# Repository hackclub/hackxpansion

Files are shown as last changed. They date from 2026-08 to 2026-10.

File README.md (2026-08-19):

<h1 align="center">
    Hackxpansion
</h1>

<h3 align="center">
    <a href="https://hackxpansion.koeg.dev">Website</a>
    <br/>
</h3>

<h4 align="center">
    A handheld console with 4 expansion solts
</h4>

<div align="center">
    
</div>

## Key Features

- Resistor based module identification at start up
- [2" 240x320 ST7789 LCD panel](https://www.buydisplay.com/2-inch-ips-tft-lcd-display-ips-panel-screen-240x320-for-smart-watch)
- RP2354 MCU
- Easily adaptable [module standard](https://hackxpansion.dino.icu/docs/detailed/card)
- Rust firmware with [embassy](https://embassy.dev/) and [slint-ui](https://slint.dev/)

## Why?

I really like the idea of modules, and modular things, and making people work together, so I made this.

## PCB

The console has two 4 layer PCBs designed in KiCAD, a main-board and a daughter-board, designed for JLC's basic process. 

irl pcb without some connectors and swithc

### Main-Board

main-board schematic
main-board pcb
main-board render

### Daughter-Board

daughter-board schematic
daughter-board pcb
daughter-board render

## Making Your Own Modules

There are three simple steps to making your own module:

1. Design the module PCB in KiCAD
2. Design the module case in CAD
3. Write a driver for the module

There are detailed docs on the [hackxpansion website](https://hackxpansion.dino.icu/docs)

## Case

The case is designed in Autodesk Fusion, there are .f3z files in the hardware directory.

The models have parameters that can be adjusted to fit your needs.

## Shoutouts

Thank you so much for [Simon](https://github.com/NEOgHacking) who helped with the fanout of the RP, and also gave a ton of constructive feedback!!!!

## Zine

magazine page

## BOM for Console

This is for an order of 2 PCBA PCBs.

Also found in a [CSV file](hardware/hackxpansion/BOM.csv). Each component has an LCSC part number attached that can be used to find the component on the LCSC website.

|Item |Price per unit|Nr of units|Total price|Link |
|---|---|---|---|---|
|PCB with PCBA |$60.00 |1 |$60.00 |https://jlcpcb.com/ |
|Display |$4.36 |1 |$4.36 |https://www.buydisplay.com/2-inch-ips-tft-lcd-display-ips-panel-screen-240x320-for-smart-watch|
|2x7 2.54mm header |$0.386 |10 |$3.860 |https://www.aliexpress.com/item/1005012166781874.html |
|Battery 502035 |$6.64 |1 |$6.64 |https://www.aliexpress.com/item/1005008218024646.html |
|M2 OD3 L2 heat set insert |$0.0696 |15 |$1.0440 |https://www.aliexpress.com/item/1005006798286851.html |
|M2 L6 screw |$0.0766 |5 |$0.3830 |https://www.aliexpress.com/item/4000970993800.html |
|M2 L8 screw |$0.0766 |2 |$0.1532 |https://www.aliexpress.com/item/4000970993800.html |
|M2 L4 screw |$0.0766 |8 |$0.6128 |https://www.aliexpress.com/item/4000970993800.html |
| | |Total: |$77.05 | |

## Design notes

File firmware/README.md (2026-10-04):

# Xpanse

> [!WARNING]  
> This is still under development and may contain bugs, and the api may change, and many parts aren't documented.

This is the firmware for the Hackxpansion console.

The main binary crate is called `xpanse`; this is the create the is the heart of the firmware.

The driver api is located in the `xpanse-api` crate; this crate provides drivers and apps with the necessary traits and types that they need to implement.

## Enabling apps

Each app can be enabled by a feature flag; you can find the exact names for these in the `Cargo.toml` of the `xpanse` folder under the `[features]` section.

You can enable features by adding `--features "app-name1,app-name2,app-name3"

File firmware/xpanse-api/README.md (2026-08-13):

# Xpanse API

Shared API for xpanse apps, module drivers, and platform firmware for the [Hackxpansion](https://github.com/hackclub/hackxpansion) console

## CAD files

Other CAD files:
hardware/hackxpansion/hackx.f3z

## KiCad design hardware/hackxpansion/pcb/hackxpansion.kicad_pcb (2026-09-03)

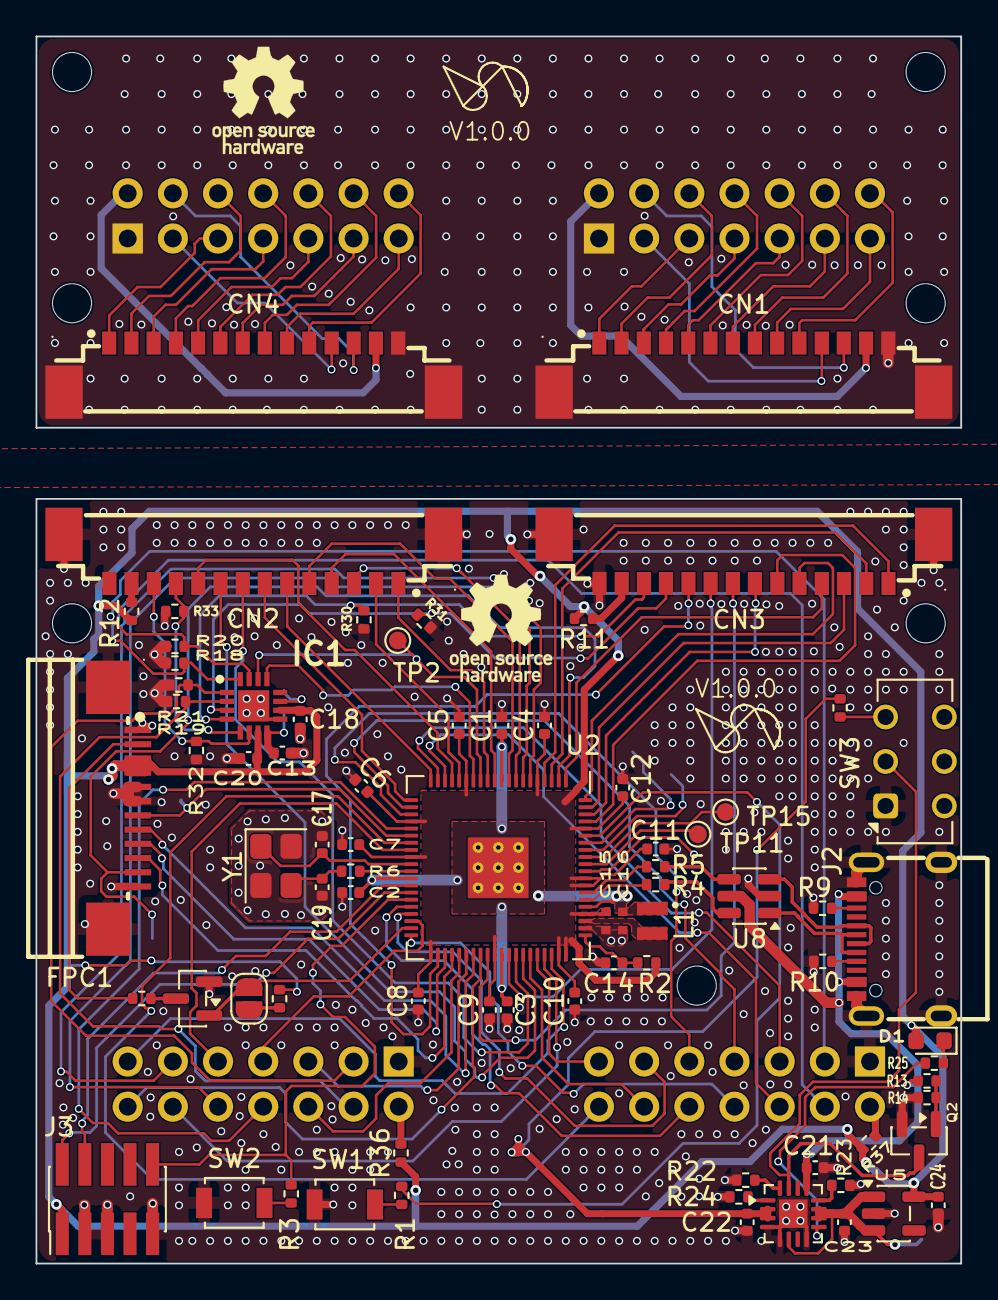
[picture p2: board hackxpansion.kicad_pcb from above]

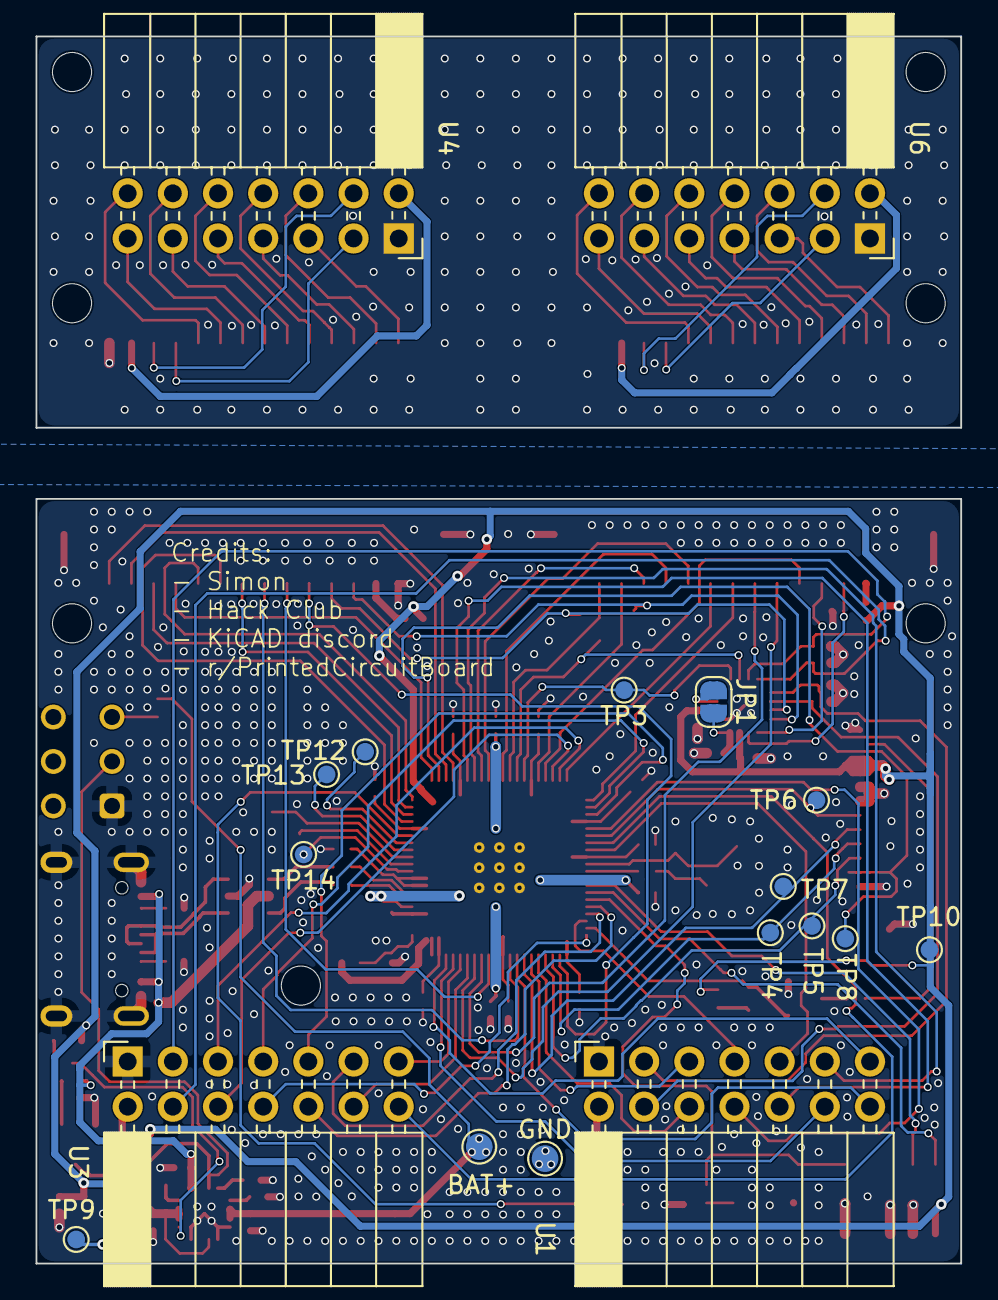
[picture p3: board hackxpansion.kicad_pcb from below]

Board: 4 copper layers, 52.0 x 43.0 mm, 104 parts (21 on the bottom side), 130 nets.

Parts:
BAT+: TestPoint; TestPoint_Pad_D1.5mm
C1, C3, C4, C5, C6, C7, C8, C9, C10, C11, C12: 100n; C_0402_1005Metric
C2, C14, C21, C22, C23, C24: 4u7; C_0402_1005Metric
C13, C18, C20: 1u; C_0402_1005Metric
C15, C16: 4u7; C_0402_1005Metric_small_pads
C17, C19: 15p; C_0402_1005Metric
CN1, CN2, CN3, CN4: 533981471; CONN-SMD_14P-P1.25_MOLEX_533981471
D1: LED; LED_0603_1608Metric
FPC1: AFC08-S12ECA-00; FPC-SMD_P0.80-12P_LCS-SJ-H2.0
GND: TestPoint; TestPoint_Pad_D1.5mm
H1, H2, H3, H4, H5, H6, H7: MountingHole; MountingHole_2.2mm_M2
IC1: ADS7128IRTET; QFN50P300X300X80-17N-D
J2: USB_C_Receptacle_USB2.0_14P; USB-C-SMD_TYPE-C-16PIN-2MD-073
J3: Conn_ARM_JTAG_SWD_10; PinHeader_2x05_P1.27mm_Vertical_SMD
JP1, JP3: SolderJumper_2_Open; SolderJumper-2_P1.3mm_Open_RoundedPad1.0x1.5mm
L1: 3u3; L_pol_2016
Q1: BSS138; SOT-23
Q2: 2N7002; SOT-23
R1, R3, R6: 1k; R_0402_1005Metric
R2: 33R; R_0402_1005Metric
R4, R5: 27R; R_0402_1005Metric
R7: 10R; R_0402_1005Metric
R8, R14, R18, R19, R20, R21, R24, R30, R31, R32, R33: 10k; R_0402_1005Metric
R9, R10: 5k1; R_0402_1005Metric
R11, R12, R36, R37: 5R1; R_0402_1005Metric
R13: 100R; R_0402_1005Metric
R15: 100k; R_0402_1005Metric
R22: 3k3; R_0402_1005Metric
R23, R25: 1k5; R_0402_1005Metric
SW1, SW2: SW_Push; SW_SPST_B3U-1000P
SW3: SW_On_Off; SW_CK_JS202011AQN_DPDT_Angled
SYM1, SYM2: Logo_Open_Hardware_Small; OSHW-Logo_5.7x6mm_SilkScreen
TP2, TP3, TP4, TP5, TP6, TP7, TP8, TP9, TP10, TP11, TP12, TP13, TP14, TP15: TestPoint; TestPoint_Pad_D1.0mm
U1, U3, U4, U6: PinSocket_2x07_P2.54mm_Horizontal
U2: RP2354B; RP2350-QFN-80-1EP_10x10_P0.4mm_EP3.4x3.4mm_ThermalVias
U5: SPX3819M5-L-3-3; SOT-23-5
U7: BQ24075RGT; VQFN-16-1EP_3x3mm_P0.5mm_EP1.6x1.6mm
U8: USBLC6-2SC6; SOT-23-6
Y1: ABM8-272-T3; Crystal_SMD_3225-4Pin_3.2x2.5mm

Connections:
+1V1: C1.1, C2.1, C3.1, C16.1, L1.1, U2.10 (DVDD), U2.32 (DVDD), U2.51 (DVDD), U2.65 (VREG_FB)
/+3V3: C4.1, C5.1, C6.1, C7.1, C8.1, C9.1, C10.1, C11.1, C12.1, C15.1, C18.1, C20.1, C24.2, D1.2 (A), FPC1.3, FPC1.4, IC1.7 (AVDD), IC1.10 (DVDD), J3.1 (VTref), R2.1, R8.2, R11.1, R12.1, R36.1, R37.1, TP10.1 (1_1), U2.5 (IOVDD), U2.15 (IOVDD), U2.24 (IOVDD), U2.29 (IOVDD), U2.41 (IOVDD), U2.50 (IOVDD), U2.59 (ADC_AVDD), U2.60 (IOVDD), U2.64 (VREG_VIN), U2.68 (USB_OTP_VDD), U2.69 (QSPI_IOVDD), U2.76 (IOVDD), U5.5 (OUT)
/Connector Daughter Mod2/bank.GPIO0: CN1.1, U4.5 (GPIO0)
/Connector Daughter Mod2/bank.GPIO1: CN1.2, U4.6 (GPIO1)
/Connector Daughter Mod2/bank.GPIO2: CN1.3, U4.7 (GPI02)
/Connector Daughter Mod2/bank.GPIO3: CN1.4, U4.8 (GPIO3)
/Connector Daughter Mod2/bank.GPIO4: CN1.5, U4.9 (GPIO4)
/Connector Daughter Mod2/bank.GPIO5: CN1.6, U4.10 (GPIO5)
/Connector Daughter Mod2/bank.GPIO6: CN1.7, U4.11 (GPIO6)
/Connector Daughter Mod2/bank.GPIO7: CN1.8, U4.12 (GPIO7)
/Connector Daughter Mod2/bank.GPIO8: CN1.9, U4.13 (GPIO8)
/Connector Daughter Mod2/bank.GPIO9: CN1.10, U4.14 (GPIO9)
/Connector Daughter Mod2/mod.MD0: CN1.11, U4.3 (MD0)
/Connector Daughter Mod2/mod.MD1: CN1.12, U4.4 (MD1)
/Connector Daughter Mod3/bank.GPIO0: CN4.1, U6.5 (GPIO0)
/Connector Daughter Mod3/bank.GPIO1: CN4.2, U6.6 (GPIO1)
/Connector Daughter Mod3/bank.GPIO2: CN4.3, U6.7 (GPI02)
/Connector Daughter Mod3/bank.GPIO3: CN4.4, U6.8 (GPIO3)
/Connector Daughter Mod3/bank.GPIO4: CN4.5, U6.9 (GPIO4)
/Connector Daughter Mod3/bank.GPIO5: CN4.6, U6.10 (GPIO5)
/Connector Daughter Mod3/bank.GPIO6: CN4.7, U6.11 (GPIO6)
/Connector Daughter Mod3/bank.GPIO7: CN4.8, U6.12 (GPIO7)
/Connector Daughter Mod3/bank.GPIO8: CN4.9, U6.13 (GPIO8)
/Connector Daughter Mod3/bank.GPIO9: CN4.10, U6.14 (GPIO9)
/Connector Daughter Mod3/mod.MD0: CN4.11, U6.3 (MD0)
/Connector Daughter Mod3/mod.MD1: CN4.12, U6.4 (MD1)
/Connector Main Mod2/+3V3: CN3.13, R11.2
/Connector Main Mod2/bank.GPIO0: CN3.1, U2.4 (GPIO7)
/Connector Main Mod2/bank.GPIO1: CN3.2, U2.3 (GPIO6)
/Connector Main Mod2/bank.GPIO2: CN3.3, U2.79 (GPIO2)
/Connector Main Mod2/bank.GPIO3: CN3.4, U2.1 (GPIO4)
/Connector Main Mod2/bank.GPIO4: CN3.5, U2.80 (GPIO3)
/Connector Main Mod2/bank.GPIO5: CN3.6, U2.77 (GPIO0)
/Connector Main Mod2/bank.GPIO6: CN3.7, U2.78 (GPIO1)
/Connector Main Mod2/bank.GPIO7: CN3.8, U2.49 (GPIO40/ADC0)
/Connector Main Mod2/bank.GPIO8: CN3.9, U2.52 (GPIO41/ADC1)
/Connector Main Mod2/bank.GPIO9: CN3.10, U2.42 (GPIO33)
/Connector Main Mod2/mod.MD0: CN3.11, IC1.3 (AIN4/GPIO4), R31.1
/Connector Main Mod2/mod.MD1: CN3.12, IC1.4 (AIN5/GPIO5), R30.1
/Connector Main Mod3/+3V3: CN2.13, R12.2
/Connector Main Mod3/bank.GPIO0: CN2.1, U2.12 (GPIO13)
/Connector Main Mod3/bank.GPIO1: CN2.2, U2.16 (GPIO16)
/Connector Main Mod3/bank.GPIO2: CN2.3, U2.8 (GPIO10)
/Connector Main Mod3/bank.GPIO3: CN2.4, U2.11 (GPIO12)
/Connector Main Mod3/bank.GPIO4: CN2.5, U2.9 (GPIO11)
/Connector Main Mod3/bank.GPIO5: CN2.6, U2.20 (GPIO20)
/Connector Main Mod3/bank.GPIO6: CN2.7, U2.21 (GPIO21)
/Connector Main Mod3/bank.GPIO7: CN2.8, U2.53 (GPIO42/ADC2)
/Connector Main Mod3/bank.GPIO8: CN2.9, U2.54 (GPIO43/ADC3)
/Connector Main Mod3/bank.GPIO9: CN2.10, U2.17 (GPIO17)
/Connector Main Mod3/mod.MD0: CN2.11, IC1.5 (AIN6/GPIO6), R33.1
/Connector Main Mod3/mod.MD1: CN2.12, IC1.6 (AIN7/GPIO7), R32.1
/DAUGHT_GND: CN1.14, CN1.15, CN1.16, CN4.14, CN4.15, CN4.16, U4.1 (GND), U6.1 (GND)
/Daughter Board/+3V3_MOD2: CN1.13, U4.2 (3V3)
/Daughter Board/+3V3_MOD3: CN4.13, U6.2 (3V3)
/GND: C1.2, C2.2, C3.2, C4.2, C5.2, C6.2, C7.2, C8.2, C9.2, C10.2, C11.2, C12.2, C13.2, C14.2, C15.2, C16.2, C17.1, C18.2, C19.1, C20.2, C21.1, C22.1, C23.1, C24.1, CN2.14, CN2.15, CN2.16, CN3.14, CN3.15, CN3.16, FPC1.1, FPC1.5, FPC1.6, FPC1.12, FPC1.13, FPC1.14, GND.1 (1_1), IC1.9 (GND), IC1.17 (EP), J2.A1 (GND), J2.A12 (GND), J2.B1 (GND), J2.B12 (GND), J2.SH (SHIELD), J3.3 (GND), J3.5 (GND), J3.9 (GNDDetect), Q1.2 (S), Q2.2 (S), R9.2, R10.2, R14.2, R18.2, R19.2, R20.2, R21.2, R22.2, R23.2, R24.2, R30.2, R31.2, R32.2, R33.2, SW1.1, SW2.1, SW3.1 (A), U1.1 (GND), U2.62 (VREG_PGND), U2.81 (GND), U3.1 (GND), U5.2 (GND), U7.4 (~CE), U7.5 (EN2), U7.8 (VSS), U7.17 (VSS), U8.2 (GND), Y1.2 (G), Y1.4 (G)
/Main Board/ADC/SCL: IC1.13 (SCL), TP3.1 (1_1), U2.14 (GPIO15)
/Main Board/ADC/SDA: IC1.14 (SDA), TP2.1 (1_1), U2.13 (GPIO14)
/Main Board/ADC/mod0.MD0: IC1.1 (AIN2/GPIO2), R21.1, U1.3 (MD0)
/Main Board/ADC/mod0.MD1: IC1.2 (AIN3/GPIO3), R19.1, U1.4 (MD1)
/Main Board/ADC/mod1.MD0: IC1.15 (AIN0/GPIO0), R20.1, U3.3 (MD0)
/Main Board/ADC/mod1.MD1: IC1.16 (AIN1/GPIO1), R18.1, U3.4 (MD1)
/Main Board/Display/BACKLIGHT: JP3.2 (B), Q1.1 (G), U2.39 (GPIO31)
/Main Board/Display/CS: FPC1.8, TP7.1 (1_1), U2.47 (GPIO38)
/Main Board/Display/DC: FPC1.7, TP6.1 (1_1), U2.26 (GPIO25)
/Main Board/Display/MOSI: FPC1.10, TP5.1 (1_1), U2.44 (GPIO35)
/Main Board/Display/RESET: FPC1.11, TP8.1 (1_1), U2.2 (GPIO5)
/Main Board/Display/SCLK: FPC1.9, TP4.1 (1_1), U2.43 (GPIO34)
/Main Board/Module Bay 0/+3V3: R36.2, U1.2 (3V3)
/Main Board/Module Bay 0/GPIO0: U1.5 (GPIO0), U2.46 (GPIO37)
/Main Board/Module Bay 0/GPIO1: U1.6 (GPIO1), U2.45 (GPIO36)
/Main Board/Module Bay 0/GPIO2: U1.7 (GPI02), U2.38 (GPIO30)
/Main Board/Module Bay 0/GPIO3: U1.8 (GPIO3), U2.25 (GPIO24)
/Main Board/Module Bay 0/GPIO4: U1.9 (GPIO4), U2.28 (GPIO27)
/Main Board/Module Bay 0/GPIO5: U1.10 (GPIO5), U2.6 (GPIO8)
/Main Board/Module Bay 0/GPIO6: U1.11 (GPIO6), U2.7 (GPIO9)
/Main Board/Module Bay 0/GPIO7: U1.12 (GPIO7), U2.57 (GPIO46/ADC6)
/Main Board/Module Bay 0/GPIO8: U1.13 (GPIO8), U2.58 (GPIO47/ADC7)
/Main Board/Module Bay 0/GPIO9: U1.14 (GPIO9), U2.48 (GPIO39)
/Main Board/Module Bay 1/+3V3: R37.2, U3.2 (3V3)
/Main Board/Module Bay 1/GPIO0: U2.19 (GPIO19), U3.5 (GPIO0)
/Main Board/Module Bay 1/GPIO1: U2.18 (GPIO18), U3.6 (GPIO1)
/Main Board/Module Bay 1/GPIO2: U2.22 (GPIO22), U3.7 (GPI02)
/Main Board/Module Bay 1/GPIO3: U2.40 (GPIO32), U3.8 (GPIO3)
/Main Board/Module Bay 1/GPIO4: U2.23 (GPIO23), U3.9 (GPIO4)
/Main Board/Module Bay 1/GPIO5: U2.36 (GPIO28), U3.10 (GPIO5)
/Main Board/Module Bay 1/GPIO6: U2.37 (GPIO29), U3.11 (GPIO6)
/Main Board/Module Bay 1/GPIO7: U2.55 (GPIO44/ADC4), U3.12 (GPIO7)
/Main Board/Module Bay 1/GPIO8: U2.56 (GPIO45/ADC5), U3.13 (GPIO8)
/Main Board/Module Bay 1/GPIO9: U2.27 (GPIO26), U3.14 (GPIO9)
/Main Board/Power/+BATT: BAT+.1 (1_1), C22.2, R15.1, U7.2 (BAT), U7.3 (BAT)
/Main Board/Power/ILIM: R23.1, U7.12 (ILIM)
/Main Board/Power/ISET: R22.1, U7.16 (ISET)
/Main Board/Power/REG-OUT: C23.2, TP9.1 (1_1), U5.1 (IN), U5.3 (EN), U7.6 (EN1), U7.10 (OUT), U7.11 (OUT)
/Main Board/Power/SYSOFF: Q2.3 (D), SW3.2 (B), U7.15 (SYSOFF)
/Main Board/Power/TS: R24.1, U7.1 (TS)
/Main Board/Power/VBUS: C21.2, J2.A4 (VBUS), J2.A9 (VBUS), J2.B4 (VBUS), J2.B9 (VBUS), R13.1, U7.13 (IN), U8.5 (VBUS)
/Main Board/RP2354B/D+: R5.1, U8.4 (I/O2)
/Main Board/RP2354B/D-: R4.1, U8.6 (I/O1)
/Main Board/RP2354B/QSPI_SS: R1.2, U2.75 (~QSPI_SS)
/Main Board/RP2354B/RUN: J3.10 (~RESET), R3.2, U2.35 (RUN)
/Main Board/RP2354B/SWCLK: J3.4 (SWCLK/TCK), U2.33 (SWCLK)
/Main Board/RP2354B/SWDIO: J3.2 (SWDIO/TMS), U2.34 (SWDIO)
/Main Board/RP2354B/~USB_BOOT: R1.1, SW1.2
/Main Board/USB/CC1: J2.A5 (CC1), R10.1
/Main Board/USB/CC2: J2.B5 (CC2), R9.1
/Main Board/USB/DIRTY_D+: J2.A6 (D+), J2.B6 (D+), U8.3 (I/O2)
/Main Board/USB/DIRTY_D-: J2.A7 (D-), J2.B7 (D-), U8.1 (I/O1)
unnamed: C19.2, R6.1, Y1.3
unnamed: D1.1 (K), R25.1
unnamed: FPC1.2, R7.2
unnamed: IC1.11 (ADDR), JP1.1 (A)
unnamed: C13.1, IC1.8 (DECAP), JP1.2 (B)
unnamed: JP3.1 (A), R8.1
unnamed: Q1.3 (D), R7.1
unnamed: Q2.1 (G), R13.2, R14.1
unnamed: R3.1, SW2.2
unnamed: R15.2, SW3.3 (C)
unnamed: TP11.1 (1_1), U2.71 (QSPI_SCLK)
unnamed: TP15.1 (1_1), U2.72 (QSPI_SD0)
unnamed: TP12.1 (1_1), U2.74 (QSPI_SD1)
unnamed: TP13.1 (1_1), U2.73 (QSPI_SD2)
unnamed: TP14.1 (1_1), U2.70 (QSPI_SD3)
unnamed: R4.2, U2.66 (USB_DM)
unnamed: R5.2, U2.67 (USB_DP)
unnamed: C14.1, R2.2, U2.61 (VREG_AVDD)
unnamed: L1.2, U2.63 (VREG_LX)
unnamed: C17.2, U2.30 (XIN), Y1.1
unnamed: R6.2, U2.31 (XOUT)
unnamed: R25.2, U7.9 (~CHG)

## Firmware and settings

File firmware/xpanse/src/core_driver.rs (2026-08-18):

use xpanse_api::gpio_bank::GpioBank;
use xpanse_api::registry::Registry;

use crate::load_driver::load_driver_pair;
use crate::{adc::init_adc, adc_mapping, resource_split::*};
use xpanse_api::bus::allocator::BusAllocator;
use xpanse_api::interfaces::adc;
use xpanse_api::interfaces::usb::UsbPeripheral;
use xpanse_api::metadata::{ModuleID, ModuleSlot};

use embassy_sync::{blocking_mutex::raw::CriticalSectionRawMutex, signal::Signal};
use embassy_time::{Duration, Timer, with_timeout};

const MODULE_DETECTION_TIMEOUT: Duration = Duration::from_millis(100);

macro_rules! gpio_bank_from_peris {
    ($peri:expr) => {
        GpioBank::new(
            $peri.gpio0,
            $peri.gpio1,
            $peri.gpio2,
            $peri.gpio3,
            $peri.gpio4,
            $peri.gpio5,
            $peri.gpio6,
            $peri.gpio7,
            $peri.gpio8,
            $peri.gpio9,
            $peri.pwm_slice1,
            $peri.pwm_slice2,
            $peri.pwm_slice3,
        )
    };
}

static REGISTRY_HANDOFF: Signal<CriticalSectionRawMutex, Registry> = Signal::new();

pub async fn take_registry() -> Registry {
    REGISTRY_HANDOFF.wait().await
}

#[embassy_executor::task]
pub async fn app_core_task(
    gpio_bank_0: GpioBankPeris0,
    gpio_bank_1: GpioBankPeris1,
    gpio_bank_2: GpioBankPeris2,
    gpio_bank_3: GpioBankPeris3,
    mut i2c_pins: I2cPinPeris,
    remaining_peris: RemainingPeris,
) {
    defmt::info!("app_core: started on core 1");

    let gpio_bank_0 = gpio_bank_from_peris!(gpio_bank_0);
    let gpio_bank_1 = gpio_bank_from_peris!(gpio_bank_1);
    let gpio_bank_2 = gpio_bank_from_peris!(gpio_bank_2);
    let gpio_bank_3 = gpio_bank_from_peris!(gpio_bank_3);
    defmt::info!("app_core: GPIO banks initialized");

    defmt::info!("app_core: initializing module-detection ADC");
    let module_ids = {
        let module_adc = match init_adc(i2c_pins.sda.reborrow(), i2c_pins.scl.reborrow()).await {
            Ok(adc) => {
                defmt::info!("app_core: module-detection ADC initialized");
                Some(adc)
            }
            Err(error) => {
                defmt::error!(
                    "app_core: module-detection ADC initialization failed: {:?}",
                    error
                );
                None
            }
        };

        match module_adc {
            Some(mut module_adc) => {
                let front_right = detect_module(&mut module_adc, ModuleSlot::FrontRight).await;
                let front_left = detect_module(&mut module_adc, ModuleSlot::FrontLeft).await;
                let back_right = detect_module(&mut module_adc, ModuleSlot::BackRight).await;
                let back_left = detect_module(&mut module_adc, ModuleSlot::BackLeft).await;
                [front_right, front_left, back_right, back_left]
            }
            None => [None; 4],
        }
    };

    defmt::info!("app_core: initializing internal ADC");
    adc::init_adc(remaining_peris.adc, remaining_peris.adc_temp);
    defmt::info!("app_core: internal ADC initialized");

    defmt::info!("app_core: creating bus allocator");
    let mut bus_allocator = BusAllocator::new(
        None,
        Some(remaining_peris.spi1),
        Some(remaining_peris.i2c0),
        Some(remaining_peris.i2c1),
        Some(remaining_peris.uart0),
        Some(remaining_peris.uart1),
        xpanse_api::bus::allocator::DmaPool {
            ch0: Some(remaining_peris.dma_ch0),
            ch1: Some(remaining_peris.dma_ch1),
            ch2: Some(remaining_peris.dma_ch2),
            ch3: Some(remaining_peris.dma_ch3),
            ch4: Some(remaining_peris.dma_ch4),
            ch5: Some(remaining_peris.dma_ch5),
            ch6: Some(remaining_peris.dma_ch6),
            ch7: Some(remaining_peris.dma_ch7),
            ch8: Some(remaining_peris.dma_ch8),
            ch9: Some(remaining_peris.dma_ch9),
            ch10: Some(remaining_peris.dma_ch10),
            ch11: Some(remaining_peris.dma_ch11),
            ch12: Some(remaining_peris.dma_ch12),
            ch13: Some(remaining_peris.dma_ch13),
            ch14: Some(remaining_peris.dma_ch14),
            ch15: Some(remaining_peris.dma_ch15),
        },
        remaining_peris.pio0,
        remaining_peris.pio1,
        remaining_peris.pio2,
    );

    let mut registry = Registry::new();
    registry.register_platform::<UsbPeripheral>(remaining_peris.usb);

    defmt::info!("app_core: loading module drivers");
    load_driver_pair(
        (
            (module_ids[0], gpio_bank_0, ModuleSlot::FrontRight),
            (module_ids[1], gpio_bank_1, ModuleSlot::FrontLeft),
        ),
        &mut registry,
        &mut bus_allocator,
    )
    .await;
    load_driver_pair(
        (
            (module_ids[2], gpio_bank_2, ModuleSlot::BackRight),
            (module_ids[3], gpio_bank_3, ModuleSlot::BackLeft),
        ),
        &mut registry,
        &mut bus_allocator,
    )
    .await;

    defmt::info!("app_core: drivers loaded, handing registry to core 0");
    REGISTRY_HANDOFF.signal(registry);
}

async fn detect_module(adc: &mut crate::adc::Adc<'_>, slot: ModuleSlot) -> Option<ModuleID> {
    defmt::info!("app_core: detecting module in {:?}", slot);

    for attempt in 1..=3 {
        match with_timeout(MODULE_DETECTION_TIMEOUT, adc_mapping::map_adc(adc, slot)).await {
            Ok(Ok(Some(id))) => {
                defmt::info!("app_core: detected module {:?} in {:?}", id, slot);
                return Some(id);
            }
            Ok(Ok(None)) => {
                defmt::info!("app_core: no module detected in {:?}", slot);
                return None;
            }
            Ok(Err(error)) => defmt::warn!(
                "app_core: module detection attempt {} failed for {:?}: {:?}",
                attempt,
                slot,
                error
            ),
            Err(_) => defmt::warn!(
                "app_core: module detection attempt {} timed out for {:?}",
                attempt,
                slot
            ),
        }
        Timer::after_millis(10).await;
    }
    defmt::error!("app_core: module detection failed for {:?}", slot);
    None
}

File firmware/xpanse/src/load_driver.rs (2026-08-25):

use xpanse_api::{
    bus::allocator::BusAllocator,
    driver::{Driver, DriverMeta},
    gpio_bank::{BankPins, GpioBank},
    metadata::{ModuleID, ModuleSlot},
    registry::Registry,
};

type Module<G> = (Option<ModuleID>, GpioBank<G>, ModuleSlot);

/// loads a dual slot driver or two single slot drivers
///
/// 0 is right, 1 is left for modules
pub async fn load_driver_pair<G1: BankPins, G2: BankPins>(
    modules: (Module<G1>, Module<G2>),
    registry: &mut Registry,
    bus: &mut BusAllocator,
) {
    match (modules.0.0, modules.1.0) {
        (None, None) => {
            defmt::warn!("No modules in slots: {:?} {:?} ", modules.0.2, modules.1.2);
        }

        (Some(right), Some(left)) if left != right => {
            load_driver(modules.0.0, modules.0.1, modules.0.2, registry, bus).await;
            load_driver(modules.1.0, modules.1.1, modules.1.2, registry, bus).await;
        }

        (Some(id), None) | (None, Some(id)) | (Some(id), Some(_)) => {
            if let Err(banks) = load_dual_slot_driver(
                Some(id),
                (modules.0.1, modules.1.1),
                (modules.0.2, modules.1.2),
                registry,
                bus,
            )
            .await
            {
                load_driver(modules.0.0, banks.0, modules.0.2, registry, bus).await;
                load_driver(modules.1.0, banks.1, modules.1.2, registry, bus).await;
            }
        }
    }
}

async fn load_driver<G: BankPins>(
    id: Option<ModuleID>,
    bank: GpioBank<G>,
    slot: ModuleSlot,
    registry: &mut Registry,
    bus: &mut BusAllocator,
) {
    match id {
        Some(id) if id == four_button_driver::FourButtonDriver::ID => {
            match four_button_driver::FourButtonDriver::create(bank, slot, registry, bus).await {
                Ok(()) => defmt::info!("Four button driver initialized in {:?}", slot),
                Err(error) => {
                    defmt::error!("Four button driver init failed in {:?}: {:?}", slot, error)
                }
            }
        }
        Some(id) if id == two_button_driver::TwoButtonDriver::ID => {
            match two_button_driver::TwoButtonDriver::create(bank, slot, registry, bus).await {
                Ok(()) => defmt::info!("Two button driver initialized in {:?}", slot),
                Err(error) => {
                    defmt::error!("Two button driver init failed in {:?}: {:?}", slot, error)
                }
            }
        }
        Some(id) if id == test_driver::TestDriver::ID => {
            match test_driver::TestDriver::create(bank, slot, registry, bus).await {
                Ok(()) => defmt::info!("Test driver initialized in {:?}", slot),
                Err(error) => {
                    defmt::error!("Test driver init failed in {:?}: {:?}", slot, error)
                }
            }
        }
        Some(id) if id == test_driver::spi_adc::SpiAdcDriver::ID => {
            match test_driver::spi_adc::SpiAdcDriver::create(bank, slot, registry, bus).await {
                Ok(()) => defmt::info!("SPI ADC driver initialized in {:?}", slot),
                Err(error) => {
                    defmt::error!("SPI ADC driver init failed in {:?}: {:?}", slot, error)
                }
            }
        }

        Some(id) if id == wardriving_driver::WarDrivingDriver::ID => {
    match wardriving_driver::WarDrivingDriver::create(bank, slot, registry, bus).await {
        Ok(()) => defmt::info!("WarDriving driver initialized in {:?}", slot),
        Err(error) => {
            defmt::error!("WarDriving driver init failed in {:?}: {:?}", slot, error)
        }
    }
}

Some(id) if id == pn532_driver::Pn532Driver::ID => {
    match pn532_driver::Pn532Driver::create(bank, slot, registry, bus).await {
        Ok(()) => defmt::info!("PN532 driver initialized in {:?}", slot),
        Err(error) => {
            defmt::error!("PN532 driver init failed in {:?}: {:?}", slot, error)
        }
    }
}

        Some(id) if id == keebxpansion::KeebDriver::ID => {
            match keebxpansion::KeebDriver::create(bank, slot, registry, bus).await {
                Ok(()) => defmt::info!("Keeb driver initialized in {:?}", slot),
                Err(error) => {
                    defmt::error!("Keeb driver init failed in {:?}: {:?}", slot, error)
                }
            }
        }
        Some(id) if id == nfcxpansion::NfcDriver::ID => {
            match nfcxpansion::NfcDriver::create(bank, slot, registry, bus).await {
                Ok(()) => defmt::info!("NFC driver initialized in {:?}", slot),
                Err(error) => {
                    defmt::error!("NFC driver init failed in {:?}: {:?}", slot, error)
                }
            }
        }
        Some(id) => defmt::warn!("unknown driver id {:?} in {:?}", id, slot),
        None => defmt::info!("no driver to load in {:?}", slot),
    }
}


/// 0 is the right, 1 is the left for tuples
async fn load_dual_slot_driver<G1: BankPins, G2: BankPins>(
    id: Option<ModuleID>,
    banks: (GpioBank<G1>, GpioBank<G2>),
    slots: (ModuleSlot, ModuleSlot),
    registry: &mut Registry,
    bus: &mut BusAllocator,
) -> Result<(), (GpioBank<G1>, GpioBank<G2>)> {
    match id {
        // Example
        // Some(id) if id == dual_slot_test_driver::DualSlotTestDriver::ID => {
        //     match dual_slot_test_driver::DualSlotTestDriver::create(banks, slots, registry, bus).await
        //     {
        //         Ok(()) => defmt::info!("dual slot test driver initialized in {:?}", slots),
        //         Err(error) => {
        //             defmt::error!("dual slot driver init failed in {:?}: {:?}", slots, error)
        //         }
        //     }
        //     // We Return Ok here, since if there is a dual slot module in a pair of slots,
        //     // it's impossible to have other modules in those slots, so the gpio banks are not returned
        //     Ok(())
        // }
        Some(_) | None => {
            defmt::warn!("no dual slot module found in slots: {:?}", slots.0);
            Err(banks)
        }
    }
}

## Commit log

2026-08-13 added new 3d models
    [Main.f3z, hackx.f3z]
2026-08-14 updated request_pio with multiple pin support
2026-08-18 implemnted dual slot drivers
2026-08-19 fixed dual slot bugs
    [driver.rs, load_driver.rs]
2026-08-19 added docs for dual slot driver
2026-08-19 added led interface
2026-08-19 added my driver
2026-08-21 added nfc driver depenancy
2026-08-21 wardriving driver added
2026-08-25 Added pn532 driver
2026-09-02 started moving resistors from daughter to main board
    [ADC.kicad_sch, daughter.kicad_sch, daughter_conn.kicad_sch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]
2026-09-03 placed resisotrs on main board
    [hackxpansion.kicad_pcb]
2026-09-03 made silk screen pretty
    [hackxpansion.kicad_pcb]
2026-09-03 replaced battery connector with test pads
    [hackxpansion.kicad_pcb, hackxpansion.kicad_sch, main.kicad_sch]
2026-09-03 added more vias, and repaced 100k with 10k
    [hackxpansion.kicad_pcb, main.kicad_sch, pwr.kicad_sch]
2026-09-03 pcb: fixed warnings
    [hackxpansion.kicad_pcb]
2026-09-03 pcb: more vias, shortened bat+ trace
    [hackxpansion.kicad_pcb]
2026-10-24 added drivers (#16)
    * adding drivers!
    * delete weird folder
    * added 3 drivers
